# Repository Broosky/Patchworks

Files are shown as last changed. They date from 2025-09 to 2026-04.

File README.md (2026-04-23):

# 💡 Patchworks

This project consists of a set of custom electronics prototyping boards designed for testing and monitoring personal electronics projects. Each board features:

- An MCU controlled LCD display.
- Voltage, current, power (V/A/W), and ambient temperature gauges.
- Regulated 3.3V, 5V, and VADJ rails (7-12 VDC) for the dual 830 tie-point breadboards.
- A main ATmega328P Arduino Uno R3 for system monitoring (e.g., temperature and fan control for the main regulator, and power safety with the main relay).

> If you found this project useful, interesting, or worth keeping an eye on, consider giving it a ⭐️.
> It helps others discover the project and motivates me to keep building and sharing more.

## 🔹 Ideas & Upcoming Changes

- Change to fixed-point arithmetic.
- Contain related variables in structs or convert to fully object-oriented to encapsulate fixed point arithmetic, LCD functions, and chip setup, among others.
- Doxygen documentation.

## 🔹 Rev 1.2 Construction

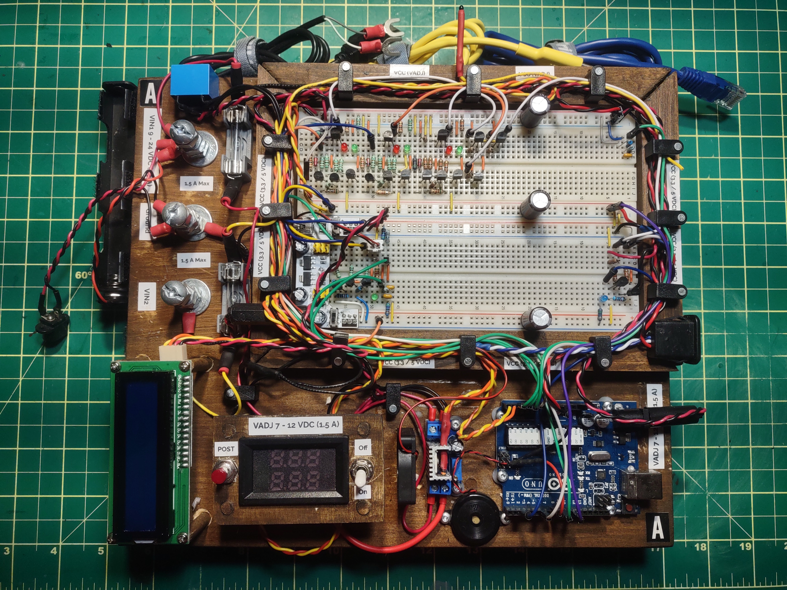
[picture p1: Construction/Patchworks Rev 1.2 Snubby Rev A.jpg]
Patchworks Rev 1.2 Snubby Rev A


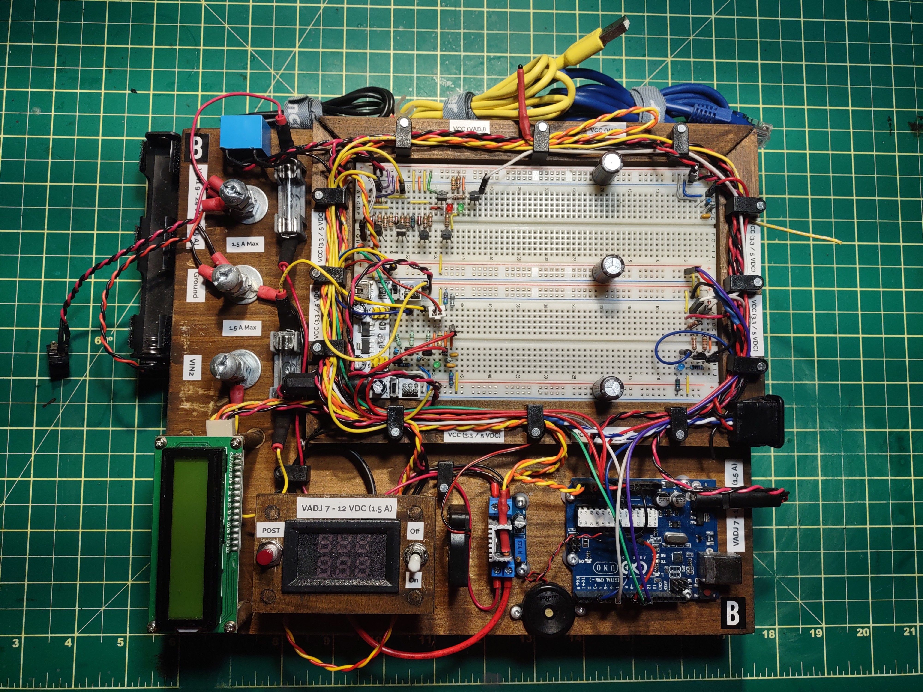
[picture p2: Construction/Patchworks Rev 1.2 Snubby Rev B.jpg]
Patchworks Rev 1.2 Snubby Rev B


## 🔹 Rev 1.2 Schematic

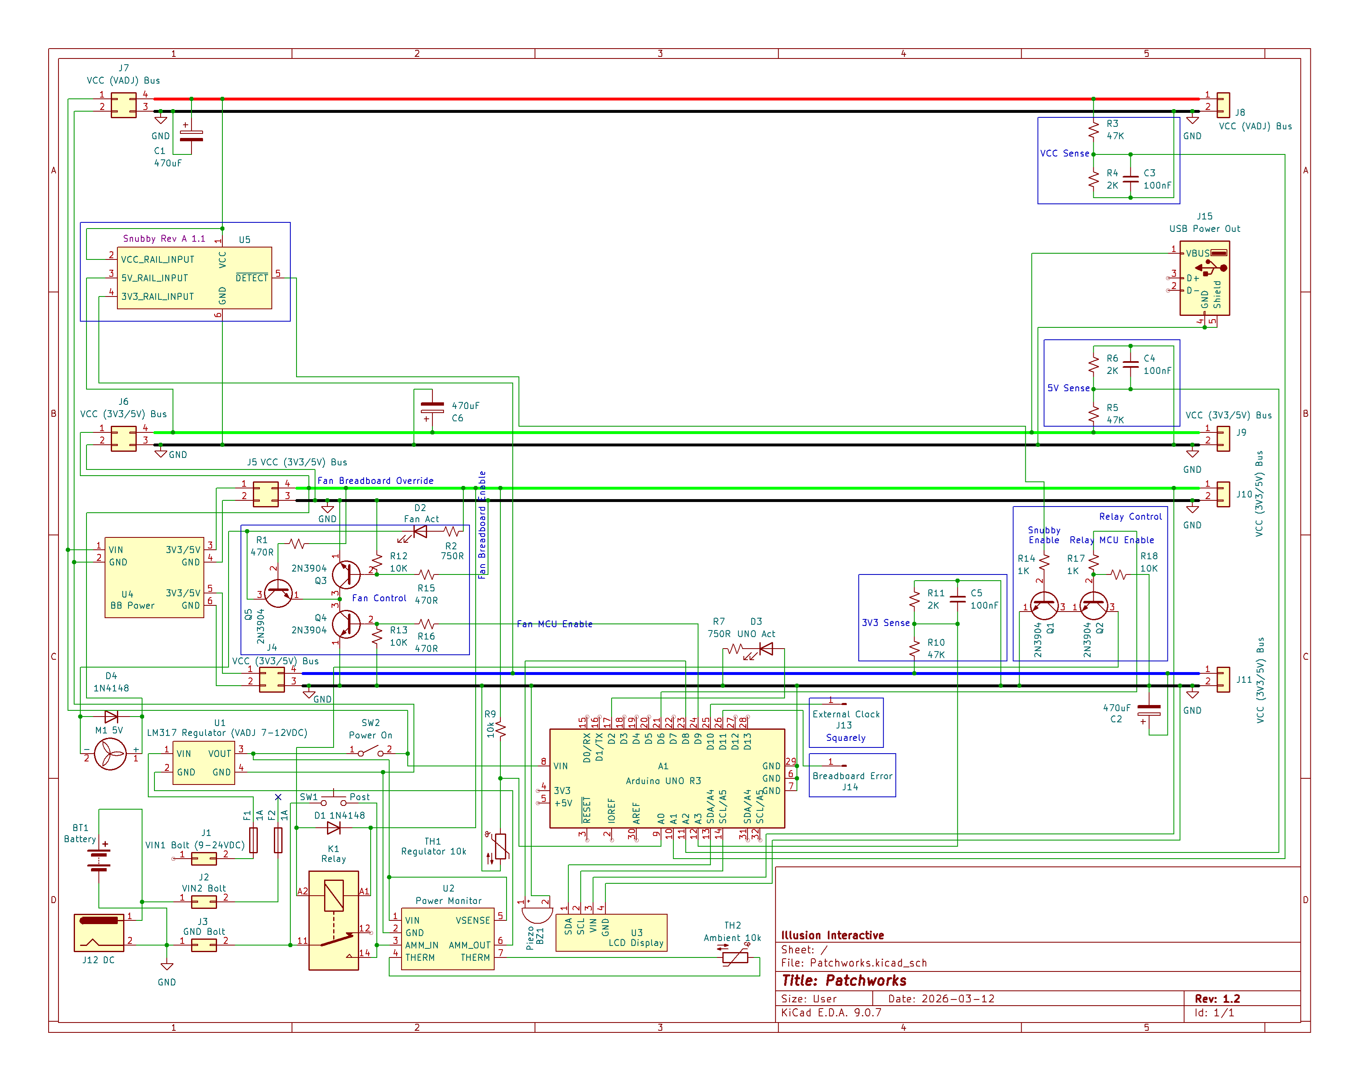
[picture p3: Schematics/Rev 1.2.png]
Rev 1.2


## 🔹 V1.4.0 Firmware For Rev 1.2 Schematic

- Voltage low/high counts + shutdown.
- Refactoring.

## 🔹 V1.3.0 Firmware For Rev 1.2 Schematic

- MCU supervised low/high voltage detection for all voltage rails.
- Hardware overvoltage detection and automatic shutdown via [Snubby](https://github.com/Broosky/Snubby).
- USB-A power output.
- MCU & manual control for the regulator fan.
- Refine allowed input voltages.
- Move fuse from GND to VIN.
- Additional flyback diode on the regulator fan.
- Remove random determinism.
- Firmware review, refactoring, and clean-up.
- Schematic labelling, VIN2 fusing.

## 🔹 Rev 1 Construction

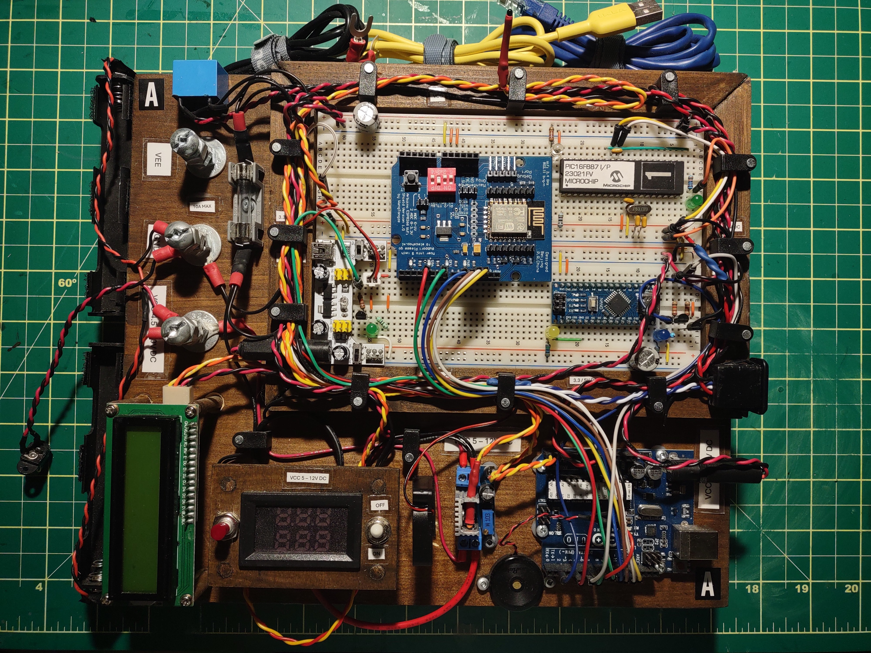
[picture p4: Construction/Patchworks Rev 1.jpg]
Patchworks Rev 1


## 🔹 Rev 1 Schematic

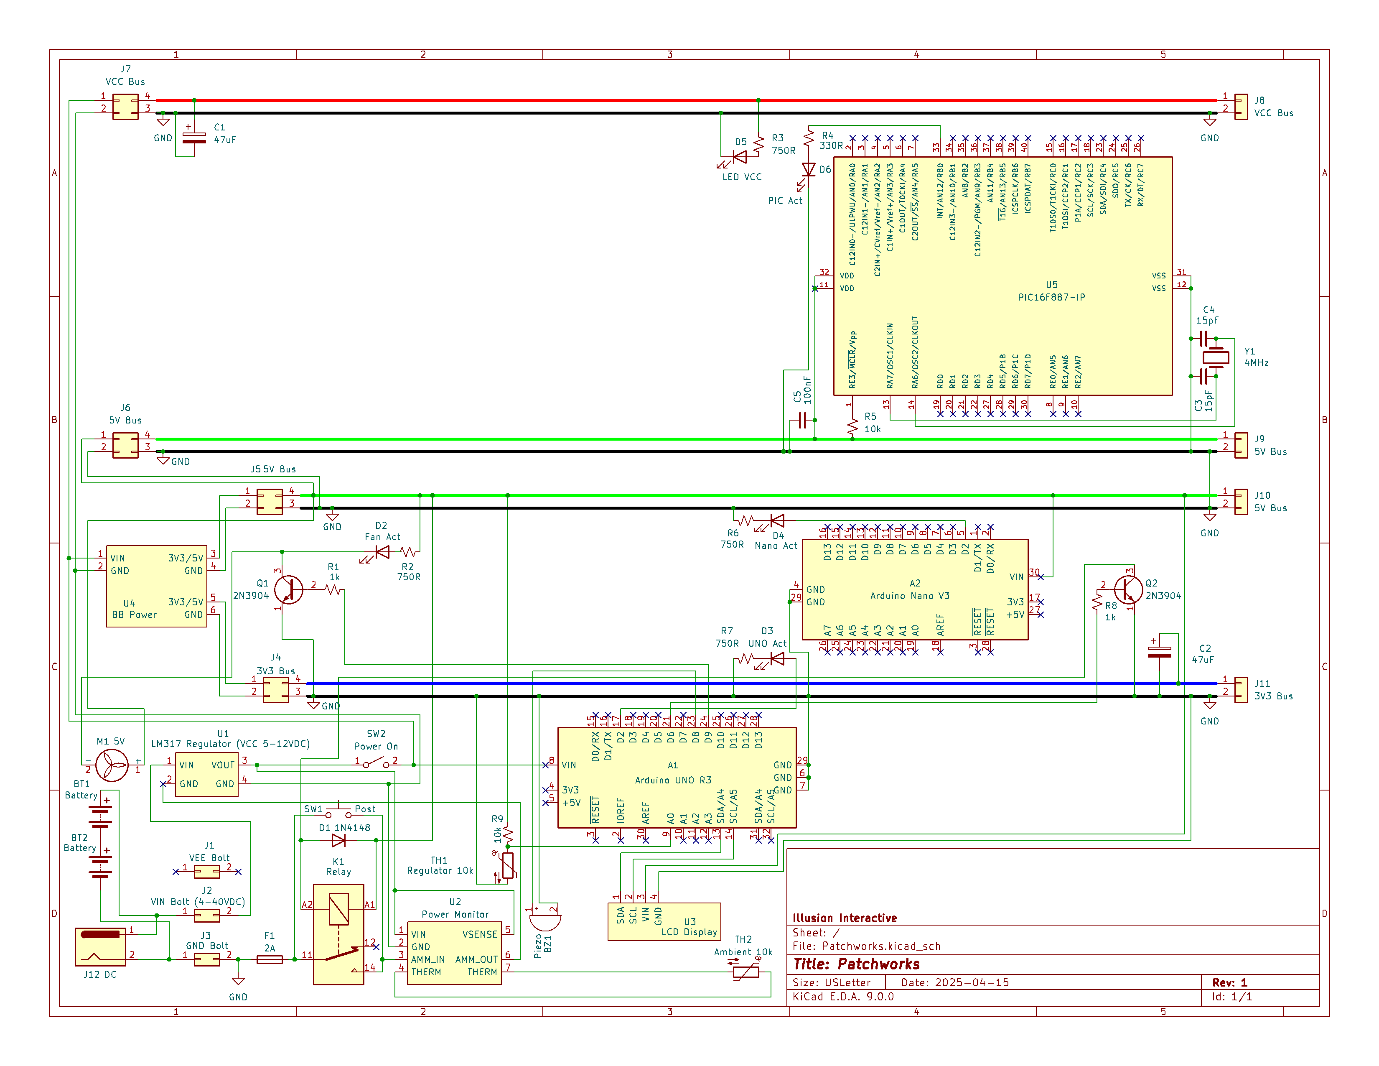
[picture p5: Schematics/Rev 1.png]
Rev 1


## 🔹 V1.2.0 Firmware For Rev 1 Schematic

- Track fan cycles, store error code in EEPROM + interrogate on startup.

## 🔹 V1.1.1 Firmware For Rev 1 Schematic

- Helpers, separations, and general review.

## 🔹 V1.0.0 Firmware For Rev 1 Schematic

- Initial release. No functional changes.

## 🔹 General Operation

- Only one power source should be used at a time (batteries, DC input, or other connections like alligator clips, etc.).
  - It is safe to power the Arduino units via USB, regardless of which external power source is selected.

- A pushbutton is used to:
  - Initiate a POST (Power-On Self-Test).
  - Verify the regulated VCC before engaging the power-on latch.

- Holding the button after the POST completes will engage the power-on latch.
- The power-on latch is managed by the main Arduino Uno and/or the breadboard electronics, allowing shutdown automatically under certain fault conditions (temperature, inefficient cooling, overvoltage).

## 🔹 Other Repositories

- Front row (to back):
  - [7Driver](https://github.com/Broosky/7Driver)
  - [Squarely](https://github.com/Broosky/Squarely)
  - Two Patchworks (this repo)

- Left side:
  - [Wattson](https://github.com/Broosky/Wattson)

- Right side:
  - Christmas tree

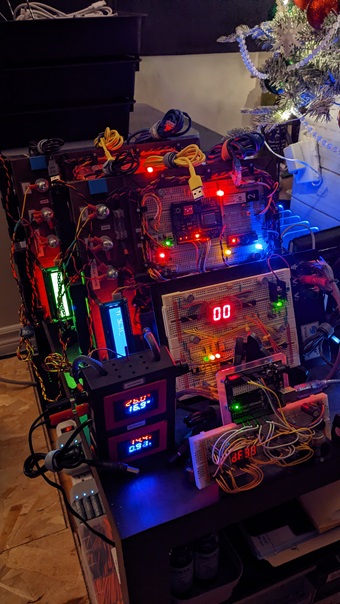
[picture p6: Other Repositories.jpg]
Other Repositories


##

> Educational Use Notice: This project is provided for educational and learning purposes only. You are welcome to read, study, and experiment
> with this software and/or hardware. It is not intended for commercial use. This software and/or hardware is provided "as is", without warranty
> of any kind. The author assumes no responsibility for any damages or issues resulting from its use.

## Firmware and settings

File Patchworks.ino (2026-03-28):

/////////////////////////////////////////////////////////////////////////////////////////////////////////////////////////////
// Project: Patchworks                                                                                                     //
// Author: Jeffrey Bednar                                                                                                  //
// Copyright (c) Illusion Interactive, 2011 - 2026.                                                                        //
/////////////////////////////////////////////////////////////////////////////////////////////////////////////////////////////
// Educational Use Notice:                                                                                                 //
/////////////////////////////////////////////////////////////////////////////////////////////////////////////////////////////
// This project is provided for educational and learning purposes only. You are welcome to read, study, and experiment     //
// with this software and/or hardware. It is not intended for commercial use. This software and/or hardware is provided    //
// "as is", without warranty of any kind. The author assumes no responsibility for any damages or issues resulting from    //
// its use.                                                                                                                //
/////////////////////////////////////////////////////////////////////////////////////////////////////////////////////////////
// Date: Tuesday, October 3rd, 2023
// Description: Source for the Patchworks electronics prototyping and monitoring board.
/////////////////////////////////////////////////////////////////////////////////////////////////////////////////////////////
// Fold all: Ctrl + K + 0
// Unfold all: Ctrl + K + J
// Show file explorer: Ctrl + Shift + E
// Auto format: Ctrl + T
/////////////////////////////////////////////////////////////////////////////////////////////////////////////////////////////
#include "Headers/fixed_point.h"
#include "Headers/lcd.h"
#include "Headers/melody.h"
#include <EEPROM.h>  // 1024 bytes available, addresses: 0 - 1023, width: 8 bits. Degrades.
/////////////////////////////////////////////////////////////////////////////////////////////////////////////////////////////
extern LiquidCrystal_I2C lcd;
/////////////////////////////////////////////////////////////////////////////////////////////////////////////////////////////
// Firmware version:
/////////////////////////////////////////////////////////////////////////////////////////////////////////////////////////////
const uint8_t FW_VERSION_MAJOR = 1;
const uint8_t FW_VERSION_MINOR = 4;
const uint8_t FW_VERSION_PATCH = 0;
/////////////////////////////////////////////////////////////////////////////////////////////////////////////////////////////
// Types:
/////////////////////////////////////////////////////////////////////////////////////////////////////////////////////////////
typedef enum ERROR_CODE : uint8_t {  // Align with ERROR_CODE_NAMES.
  ERROR_CODE_NONE,                   // No error, ignore.
  ERROR_CODE_INVALID,                // Invalid
  ERROR_CODE_HOT_CYCLES,             // Too many cycles at or above maximum temperature.
  ERROR_CODE_COOLDOWN,               // Expected cooling duration exceeded. This could also trigger if the 5V rail sags. The 5V
                                     // (and/or the 3V3) rail coud sag due to a bad output capacitor or even a failing regulator.
                                     // As such, if the fan is triggered under normal operation the 5V rail can't supply enough power
                                     // to it, so the cooldown duration can exceed the threshold.
  ERROR_CODE_BREADBOARD,             // The breadboard circuitry is commanding the MCU to shutdown the power.
  ERROR_CODE_VOLTAGE_HIGH_COUNT,     // Too many cycles for a rail to be at high voltage.
  ERROR_CODE_VOLTAGE_LOW_COUNT,      // Too many cycles for a rail to be at low voltage.
  ERROR_CODE_COUNT                   // Must be last; for iterating/bounds.
} ERROR_CODE_T;
/////////////////////////////////////////////////////////////////////////////////////////////////////////////////////////////
typedef struct F_EXTREMA {
  float min;
  float max;
} F_EXTREMA_T;
/////////////////////////////////////////////////////////////////////////////////////////////////////////////////////////////
typedef struct I32_EXTREMA {
  int32_t min;
  int32_t max;
} I32_EXTREMA_T;
/////////////////////////////////////////////////////////////////////////////////////////////////////////////////////////////
typedef struct UI32_EXTREMA {
  uint32_t min;
  uint32_t max;
} UI32_EXTREMA_T;
/////////////////////////////////////////////////////////////////////////////////////////////////////////////////////////////
// Program constants:
/////////////////////////////////////////////////////////////////////////////////////////////////////////////////////////////
const uint8_t PIN_OUTPUT_BUZZER = 8;
const uint8_t PIN_OUTPUT_FAN_ENABLE = 9;
const uint8_t PIN_OUTPUT_RELAY_ENABLE = 6;
const uint8_t PIN_OUTPUT_PROGRAM_ACTIVE = 2;
const uint8_t PIN_OUTPUT_EXTERNAL_CLOCK = 10;
/////////////////////////////////////////////////////////////////////////////////////////////////////////////////////////////
const uint8_t PIN_INPUT_VCC_SENSE = A1;
const uint8_t PIN_INPUT_5V_SENSE = A2;
const uint8_t PIN_INPUT_3V3_SENSE = A3;
const uint8_t PIN_INPUT_THERMISTOR_SENSE = A0;
const uint8_t PIN_INPUT_BREADBOARD_ERROR_SENSE = 11;
/////////////////////////////////////////////////////////////////////////////////////////////////////////////////////////////
const uint8_t VOLTAGE_READ_SAMPLES = 16;
const float VOLTAGE_BANDGAP_REFERENCE = 1.1;  // Should be measured per MCU as this varies.
const float VOLTAGE_DIVIDER_R1 = 47000.0;     // Common across VCC, 5V, and 3V3 voltage rails (1% tolerance). Allows safe input readings
                                              // for comparison with the bandgap if VCC reaches up to 24V. Although the
                                              // Arduino regulator supports up to 12V, this provides additional survivability
                                              // in the event if the main VCC regulator fails or there's a rail short. Regardless, the
                                              // hardware overvoltage protection will trigger at approximately 12.7V, 5.8V,
                                              // and 4.0V for each respective rail.
const float VOLTAGE_DIVIDER_R2 = 2000.0;
const uint8_t VOLTAGE_LOW_MAXIMUM_CYCLE_COUNT = 5;
const uint8_t VOLTAGE_HIGH_MAXIMUM_CYCLE_COUNT = 5;
/////////////////////////////////////////////////////////////////////////////////////////////////////////////////////////////
const float TEMP_ZERO_KELVIN = 273.15;
const float TEMP_LOWERBOUND = 37.00;                   // Celcius: fan off, single chirp.
const float TEMP_UPPERBOUND = 41.00;                   // Celcius: fan on until lowerbound is reached, multiple chirps.
const float TEMP_MAXIMUM = 50.0;                       // Celcius: fan on, different chirp tone. If enough cycles at or above
                                                       // this temperature, the board will automatically shut down.
const uint8_t TEMP_MAXIMUM_CYCLE_COUNT = 5;            // Number of cycles above maximum temperature before auto shut down.
const uint8_t TEMP_COOLDOWN_MAX_MINUTES = 3;           // Number of minutes to allow cooling to the lowerbound temperature
                                                       // before automatically shutting down.
const uint8_t THERMISTOR_NOMINAL_TEMPERATURE = 25;     // Almost always 25 degrees C; check datasheet.
const uint8_t THERMISTOR_READ_SAMPLES = 16;            // How many times the voltage is read before deciding an average value.
const uint16_t THERMISTOR_NOMINAL_RESISTANCE = 10000;  // Ohms
const uint16_t THERMISTOR_BETA = 3950;                 // Datasheet
const uint16_t THERMISTOR_REFERENCE = 10000;           // Ohms; resistor in the voltage divider.
/////////////////////////////////////////////////////////////////////////////////////////////////////////////////////////////
const uint16_t DELAY_LOOP_COMPLETED = 750;  // MS
const uint16_t DELAY_LCD_PAGE_CYCLE = 1850;
/////////////////////////////////////////////////////////////////////////////////////////////////////////////////////////////
const int32_t EXTERNAL_CLOCK_LOWERBOUND = 0;
const int32_t EXTERNAL_CLOCK_UPPERBOUND = 99;
/////////////////////////////////////////////////////////////////////////////////////////////////////////////////////////////
const char* ERROR_CODE_NAMES[] = {
  "None",  // Align with ERROR_CODE.
  "Invalid",
  "Hot Cycles",
  "Cooldown",
  "Breadboard",
  "Vlt H Count",
  "Vlt L Count"
};
/////////////////////////////////////////////////////////////////////////////////////////////////////////////////////////////
const F_EXTREMA_T thresholdsMcu = { .min = 4.25, .max = 5.75 };
const F_EXTREMA_T thresholdsVcc = { .min = 11.25, .max = 12.75 };
const F_EXTREMA_T thresholds5V = { .min = 4.25, .max = 5.75 };
const F_EXTREMA_T thresholds3V3 = { .min = 2.8, .max = 3.7 };
/////////////////////////////////////////////////////////////////////////////////////////////////////////////////////////////
// Program globals and counters:
/////////////////////////////////////////////////////////////////////////////////////////////////////////////////////////////
uint16_t fanCycleCount = 0;                                       // Cumulative, never resets.
uint8_t tempHighCycleCount = 0;                                   // Cumulative, never resets.
F_EXTREMA_T voltageMcuExtrema = { .min = 999.9, .max = -999.9 };  // Inverted to normalize during runtime.
F_EXTREMA_T voltageVccExtrema = { .min = 999.9, .max = -999.9 };
F_EXTREMA_T voltage5VExtrema = { .min = 999.9, .max = -999.9 };
F_EXTREMA_T voltage3V3Extrema = { .min = 999.9, .max = -999.9 };
F_EXTREMA_T tempLifetimeExtrema = { .min = 999.9, .max = -999.9 };
I32_EXTREMA_T externalClockLifetimeExtrema = { .min = EXTERNAL_CLOCK_UPPERBOUND << 1, .max = -(EXTERNAL_CLOCK_UPPERBOUND << 1) };
UI32_EXTREMA_T voltageMcuThresholdCounts;
UI32_EXTREMA_T voltageVccThresholdCounts;
UI32_EXTREMA_T voltage5VThresholdCounts;
UI32_EXTREMA_T voltage3V3ThresholdCounts;
UI32_EXTREMA_T cooldownDurationLifetimeMsExtrema = { .min = UINT32_MAX, .max = 0 };
uint8_t showSplashScreen = true;
uint8_t showLastKnownError = true;
uint32_t loopCount = 0;
/////////////////////////////////////////////////////////////////////////////////////////////////////////////////////////////
// Main program initialization.
/////////////////////////////////////////////////////////////////////////////////////////////////////////////////////////////
void setup(void) {
  ///////////////////////////////////////////////////////////////////////////////////////////////////////////////////////////
  // Ideally the internal bandgap reference is configured once on setup, but due to imported libraries and
  // other code there is contention and will need to be explicitly set prior to measurements.
  ///////////////////////////////////////////////////////////////////////////////////////////////////////////////////////////
  // Set pin modes.
  ///////////////////////////////////////////////////////////////////////////////////////////////////////////////////////////
  // Outputs:
  ///////////////////////////////////////////////////////////////////////////////////////////////////////////////////////////
  pinMode(PIN_OUTPUT_PROGRAM_ACTIVE, OUTPUT);
  pinMode(PIN_OUTPUT_BUZZER, OUTPUT);
  pinMode(PIN_OUTPUT_FAN_ENABLE, OUTPUT);
  pinMode(PIN_OUTPUT_RELAY_ENABLE, OUTPUT);
  pinMode(PIN_OUTPUT_EXTERNAL_CLOCK, OUTPUT);
  ///////////////////////////////////////////////////////////////////////////////////////////////////////////////////////////
  // Inputs:
  ///////////////////////////////////////////////////////////////////////////////////////////////////////////////////////////
  pinMode(PIN_INPUT_VCC_SENSE, INPUT);
  pinMode(PIN_INPUT_5V_SENSE, INPUT);
  pinMode(PIN_INPUT_3V3_SENSE, INPUT);
  pinMode(PIN_INPUT_THERMISTOR_SENSE, INPUT);
  pinMode(PIN_INPUT_BREADBOARD_ERROR_SENSE, INPUT_PULLUP);
  ///////////////////////////////////////////////////////////////////////////////////////////////////////////////////////////
  // Init LCD.
  ///////////////////////////////////////////////////////////////////////////////////////////////////////////////////////////
  lcd.init();
  lcd.clear();
  ///////////////////////////////////////////////////////////////////////////////////////////////////////////////////////////
  setupSeed();
  ///////////////////////////////////////////////////////////////////////////////////////////////////////////////////////////
  // Test LCD, buzzer, fan, and set power-on latch.
  ///////////////////////////////////////////////////////////////////////////////////////////////////////////////////////////
  testLcd(3, 150, 25);
  testBuzzer(&melodyTest);
  testThermistorFan(3, 500);
  setPowerOnLatch(HIGH);
}
/////////////////////////////////////////////////////////////////////////////////////////////////////////////////////////////
// Main program loop.
/////////////////////////////////////////////////////////////////////////////////////////////////////////////////////////////
void loop(void) {
  handleSplashScreen(DELAY_LCD_PAGE_CYCLE);
  handleLastKnownError(DELAY_LCD_PAGE_CYCLE, &melodyShutdown);
  handleLoopStart(DELAY_LCD_PAGE_CYCLE);
  handleBreadboardError();

  handleExternalClock(EXTERNAL_CLOCK_LOWERBOUND,
                      EXTERNAL_CLOCK_UPPERBOUND,
                      0,
                      DELAY_LCD_PAGE_CYCLE);

  float currentTemperature = handleThermistor(true,
                                              true,
                                              DELAY_LCD_PAGE_CYCLE);
  handleThermistorFan(currentTemperature,
                      TEMP_LOWERBOUND,
                      TEMP_UPPERBOUND,
                      TEMP_MAXIMUM,
                      TEMP_COOLDOWN_MAX_MINUTES,
                      DELAY_LCD_PAGE_CYCLE);

  handleVoltageReadings(DELAY_LCD_PAGE_CYCLE);

  handleUptime(DELAY_LCD_PAGE_CYCLE);

  handleLoopEnd(DELAY_LOOP_COMPLETED);
}
/////////////////////////////////////////////////////////////////////////////////////////////////////////////////////////////
// Seed by mixing analog noise and runtime for a higher degree of entropy.
/////////////////////////////////////////////////////////////////////////////////////////////////////////////////////////////
void setupSeed(void) {
  unsigned long seed = 0;

  for (uint8_t i = 0; i < 32; i++) {
    for (uint8_t pin = A0; pin <= A5; pin++) {
      seed ^= analogRead(pin) << (i % 16);
    }
    seed ^= micros();
    delay(5);
  }

  randomSeed(seed);
}
/////////////////////////////////////////////////////////////////////////////////////////////////////////////////////////////
// Check and warn if Snubby or other breadboard circuitry is reporting an error (active low).
/////////////////////////////////////////////////////////////////////////////////////////////////////////////////////////////
void handleBreadboardError(void) {
  uint8_t breadboardError = digitalRead(PIN_INPUT_BREADBOARD_ERROR_SENSE);

  if (!breadboardError) {
    shutdown(ERROR_CODE_BREADBOARD, NULL);
  }
}
/////////////////////////////////////////////////////////////////////////////////////////////////////////////////////////////
const char* const getErrorCodeName(ERROR_CODE_T errorCode) {
  if (errorCode >= ERROR_CODE_NONE && errorCode < ERROR_CODE_COUNT) {
    return ERROR_CODE_NAMES[errorCode];
  }
  return "UNKNOWN";
}
/////////////////////////////////////////////////////////////////////////////////////////////////////////////////////////////
// Generates a random number of deterministic clock cycles to be output to the external CC. For Squarely's U6 CP0 (pin 14).
/////////////////////////////////////////////////////////////////////////////////////////////////////////////////////////////
void handleExternalClock(int32_t rangeLowerbound, int32_t rangeUpperbound, uint8_t clockLengthMs, uint16_t lcdPageCycleDelayMs) {
  int32_t randomNumber = random(rangeLowerbound, rangeUpperbound + 1);

  if (randomNumber < externalClockLifetimeExtrema.min) {
    externalClockLifetimeExtrema.min = randomNumber;
  }
  if (randomNumber > externalClockLifetimeExtrema.max) {
    externalClockLifetimeExtrema.max = randomNumber;
  }

  if (randomNumber > 0) {
    for (int32_t i = 0; i < randomNumber; i++) {
      digitalWrite(PIN_OUTPUT_EXTERNAL_CLOCK, HIGH);
      if (clockLengthMs > 0) {
        delay(clockLengthMs);
      }
      digitalWrite(PIN_OUTPUT_EXTERNAL_CLOCK, LOW);
      if (i < randomNumber - 1) {
        if (clockLengthMs > 0) {
          delay(clockLengthMs);
        }
      }
    }
  }

  // Write the number and the lifetime min/max.
  printLabeledInt32(0, 0, "C: ", randomNumber, true, lcdPageCycleDelayMs);
  printLabeledInt32(0, 0, "Cmin: ", externalClockLifetimeExtrema.min, true, 0);
  printLabeledInt32(0, 1, "Cmax: ", externalClockLifetimeExtrema.max, false, lcdPageCycleDelayMs);
}
/////////////////////////////////////////////////////////////////////////////////////////////////////////////////////////////
// Engages the power-on latch to keep the board powered automatically.
/////////////////////////////////////////////////////////////////////////////////////////////////////////////////////////////
void setPowerOnLatch(uint8_t state) {
  digitalWrite(PIN_OUTPUT_RELAY_ENABLE, state);
}
/////////////////////////////////////////////////////////////////////////////////////////////////////////////////////////////
// Cycles the power regulator cooling fan for test.
/////////////////////////////////////////////////////////////////////////////////////////////////////////////////////////////
void testThermistorFan(uint8_t cycles, uint16_t fanCycleDelayMs) {
  for (uint8_t i = 0; i < cycles; i++) {
    digitalWrite(PIN_OUTPUT_FAN_ENABLE, HIGH);
    delay(fanCycleDelayMs);
    digitalWrite(PIN_OUTPUT_FAN_ENABLE, LOW);
    if (i < cycles - 1) {
      delay(1500);  // Let it come to a stop.
    }
  }
}
/////////////////////////////////////////////////////////////////////////////////////////////////////////////////////////////
// Plays a test tone for the buzzer.
/////////////////////////////////////////////////////////////////////////////////////////////////////////////////////////////
void testBuzzer(const MELODY_T* const melody) {
  playMelody(melody);
}
/////////////////////////////////////////////////////////////////////////////////////////////////////////////////////////////
// Plays a tone on the board's buzzer.
/////////////////////////////////////////////////////////////////////////////////////////////////////////////////////////////
void playMelody(const MELODY_T* const melody) {
  for (uint8_t i = 0; i < melody->cycles; i++) {
    tone(PIN_OUTPUT_BUZZER, melody->frequency, melody->durationMs);
    if (i < melody->cycles - 1) {
      // Wait until the tone finishes.
      delay(melody->durationMs);
      delay(melody->toneCycleDelayMs);
    }
  }

  // Avoid buzzer chirp during other transistions.
  if (melody->pauseBeforeReturn) {
    delay(100);
  }
}
/////////////////////////////////////////////////////////////////////////////////////////////////////////////////////////////
// Main error handler.
/////////////////////////////////////////////////////////////////////////////////////////////////////////////////////////////
void shutdown(ERROR_CODE_T errorCode, const uint32_t* const errorFlags) {
  // Playing the tone acts as the LCD page delay.
  printLabeledUInt8(0, 0, "E: ", errorCode, true, 0);
  printLabeledString(0, 1, "E: ", getErrorCodeName(errorCode), false, 0);

  size_t address = 0;
  EEPROM.put(address, errorCode);
  address += sizeof(errorCode);

  if (errorFlags) {
    EEPROM.put(address, *errorFlags);
    address += sizeof(*errorFlags);
  }

  playMelody(&melodyShutdown);
  delay(5000);

  // Self-terminate.
  setPowerOnLatch(LOW);
}
/////////////////////////////////////////////////////////////////////////////////////////////////////////////////////////////
// Displays a splash screen on the LCD.
/////////////////////////////////////////////////////////////////////////////////////////////////////////////////////////////
void handleSplashScreen(uint16_t lcdPageCycleDelayMs) {
  if (showSplashScreen) {
    char version[16], date[16], time[16];

    printString(0, 0, "Illusion", true, 0);
    printString(0, 1, "Interactive", false, lcdPageCycleDelayMs);

    snprintf(version, sizeof(version), "v%" PRIu8 ".%" PRIu8 ".%" PRIu8, FW_VERSION_MAJOR, FW_VERSION_MINOR, FW_VERSION_PATCH);

    printString(0, 0, "Patchworks", true, 0);
    printString(0, 1, version, false, lcdPageCycleDelayMs);

    snprintf(date, sizeof(date), "%s", __DATE__);
    snprintf(time, sizeof(date), "%s", __TIME__);

    printString(0, 0, date, true, 0);
    printString(0, 1, time, false, lcdPageCycleDelayMs);

    showSplashScreen = false;
  }
}
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

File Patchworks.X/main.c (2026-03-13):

/////////////////////////////////////////////////////////////////////////////////////////////////////////////////////////////
// Project: Patchworks                                                                                                     //
// Author: Jeffrey Bednar                                                                                                  //
// Copyright (c) Illusion Interactive, 2011 - 2026.                                                                        //
/////////////////////////////////////////////////////////////////////////////////////////////////////////////////////////////
// Educational Use Notice:                                                                                                 //
/////////////////////////////////////////////////////////////////////////////////////////////////////////////////////////////
// This project is provided for educational and learning purposes only. You are welcome to read, study, and experiment     //
// with this software and/or hardware. It is not intended for commercial use. This software and/or hardware is provided    //
// "as is", without warranty of any kind. The author assumes no responsibility for any damages or issues resulting from    //
// its use.                     																						   //
/////////////////////////////////////////////////////////////////////////////////////////////////////////////////////////////
#include <xc.h>
/////////////////////////////////////////////////////////////////////////////////////////////////////////////////////////////
// Configuration bits: Internal Oscillator, Watchdog Timer Off, Power-up Timer On, Code Protection Off
/////////////////////////////////////////////////////////////////////////////////////////////////////////////////////////////
#pragma config FOSC = XT    // Oscillator Selection bits (XT oscillator)
#pragma config WDTE = OFF   // Watchdog Timer Enable bit (WDT disabled)
#pragma config PWRTE = ON   // Power-up Timer Enable bit (PWRT enabled)
#pragma config BOREN = ON   // Brown-out Reset Enable bit (BOR enabled)
#pragma config LVP = OFF    // Low-Voltage (single-supply) In-Circuit Serial Programming Enable bit (RB3/PGM pin has PGM function, low-voltage programming disabled)
#pragma config CPD = OFF    // Data EEPROM Memory Code Protection bit (Data EEPROM code protection off)
#pragma config WRT = OFF    // Flash Program Memory Write Enable bits (Write protection off)
#pragma config CP = OFF     // Flash Program Memory Code Protection bit (Code protection off)
#define _XTAL_FREQ 4000000  // 4 MHz
/////////////////////////////////////////////////////////////////////////////////////////////////////////////////////////////
void main(void) {
    TRISBbits.TRISB0 = 0;   // Set RB0 as output
    while (1) {
        PORTBbits.RB0 = 1;  // Cycle PIC Activity LED.
        __delay_ms(500);
        PORTBbits.RB0 = 0;
        __delay_ms(500);
    }
}
/////////////////////////////////////////////////////////////////////////////////////////////////////////////////////////////

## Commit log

2025-09-02 Structure, schematic date
    [Patchworks.kicad_sch]
2026-03-13 Firmware and schematic updates
    [Patchworks.kicad_sch]
2026-03-28 Voltage low/high shutdown
2026-04-23 Update Patchworks
    [Patchworks.kicad_sch]
